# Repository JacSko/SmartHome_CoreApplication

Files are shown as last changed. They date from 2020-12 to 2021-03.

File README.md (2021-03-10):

# SmartHome CoreApplication

## Description
The idea of the project is to gain simple control over home appliance (like lighting).
Main board was desgined to use STM32F411CEU MCU. It communicates with other boards (list below) using different interfaces (I2C, OneWire, USART).
The main responsibility of this part of project is to ensure informations about current temperature and humidity and appliance state.

github_core_diagram

**Main board is connected with:**
- **Relays board** - equipped with 16 relays, supports either 12VDC and 230VAC switching. Board allows to e.g control light state in all rooms. Connection over I2C bus.
- **Inputs board** - board designed to handle 16 inputs (8x 12VDC, 8x 230VAC). Connection over I2C bus with interrupt fired on each input state changed. The bouncing of inputs state has been resolved either by adding debouce capacitor and programatically, by delaying inputs state readout.
- **LED's board** - board equipped with 16 outputs to control led ambient light on staircase placed near to steps. It allows to achieve some lighting effects since can be controlled independently.
- **Sensors board** - Board, where temperature and humidity sensors (DHT11/DHT22 - type is auto-detected in application), also light intense sensor is connected. The communication is realized over OneWire interface, when light intense sensor signal is send in pure analogue form.

## Details
This module is not able to present gathered data.
There is another project [SmartHome_RPi](https://github.com/JacSko/SmartHome_RPi) responsible for presenting received data.
The communication with CoreApplication can be done in two ways:
- **Over WiFi** - ESP01 module is onboard, on startup it creates TCP server, where the RaspberryPi can connects and gets the data. Messages are send in raw bytes mode (for protocol specification see notification_manager.h)
- **Over Bluetooth** - this channel is desgined mainly to provide debug traces, but there are several commands that can be issued in string-based, human readable form (see doc/ dirextory for documntation details)

Project build is managed by CMake.
Core application was prepared using CMSIS bare-metal library without dependencies to external libraries (only appropriate header files are required, but those are part of repository).
Project contains also unit tests, where the original MCU header files has been stubbed to allow compilation.

github_core_sw_diagram

## Building
### Building for target
To build binary, You need to have:
- the arm-none-eabi toolchain
- The st-linkv2 drivers (can be compiled from sources)
- The ST-FLASH utility installed
Once all of those step are ready:
```
cd <project_dir>
mkdir build && cd build
cmake ..
make
```
After the binary can be flashed by issuing:
```
make write
```
### Building Simulation
For details how to use this target, see [SmartHome_Tests](https://github.com/JacSko/SmartHome_Tests)
```
cd <project_dir>
mkdir build_sim
cd build_sim
cmake .. -DSIMULATION=On
make
```
### Building Unit tests
To build unit test, You have to clone googletest repo:
```
cd <project_dir>
cd ext_lib/googletest
git clone https://github.com/google/googletest.git
```
Than run script:
```
./build_and_run_ut.sh
```
### Coverage calculation
Run script:
```
./build_and_run_coverage.sh
```
HTML report will be opened automatically in Firefox, but it can be also found:
```
build_ut/html/coverage.html
```
## TODO
- [ ] EEPROM handling
- [ ] Settings rework to allow read/write settings from EEPROM
- [ ] ADC driver (power supply voltage, light intensity)
- [ ] Flashing over UART (from RaspberryPi module)

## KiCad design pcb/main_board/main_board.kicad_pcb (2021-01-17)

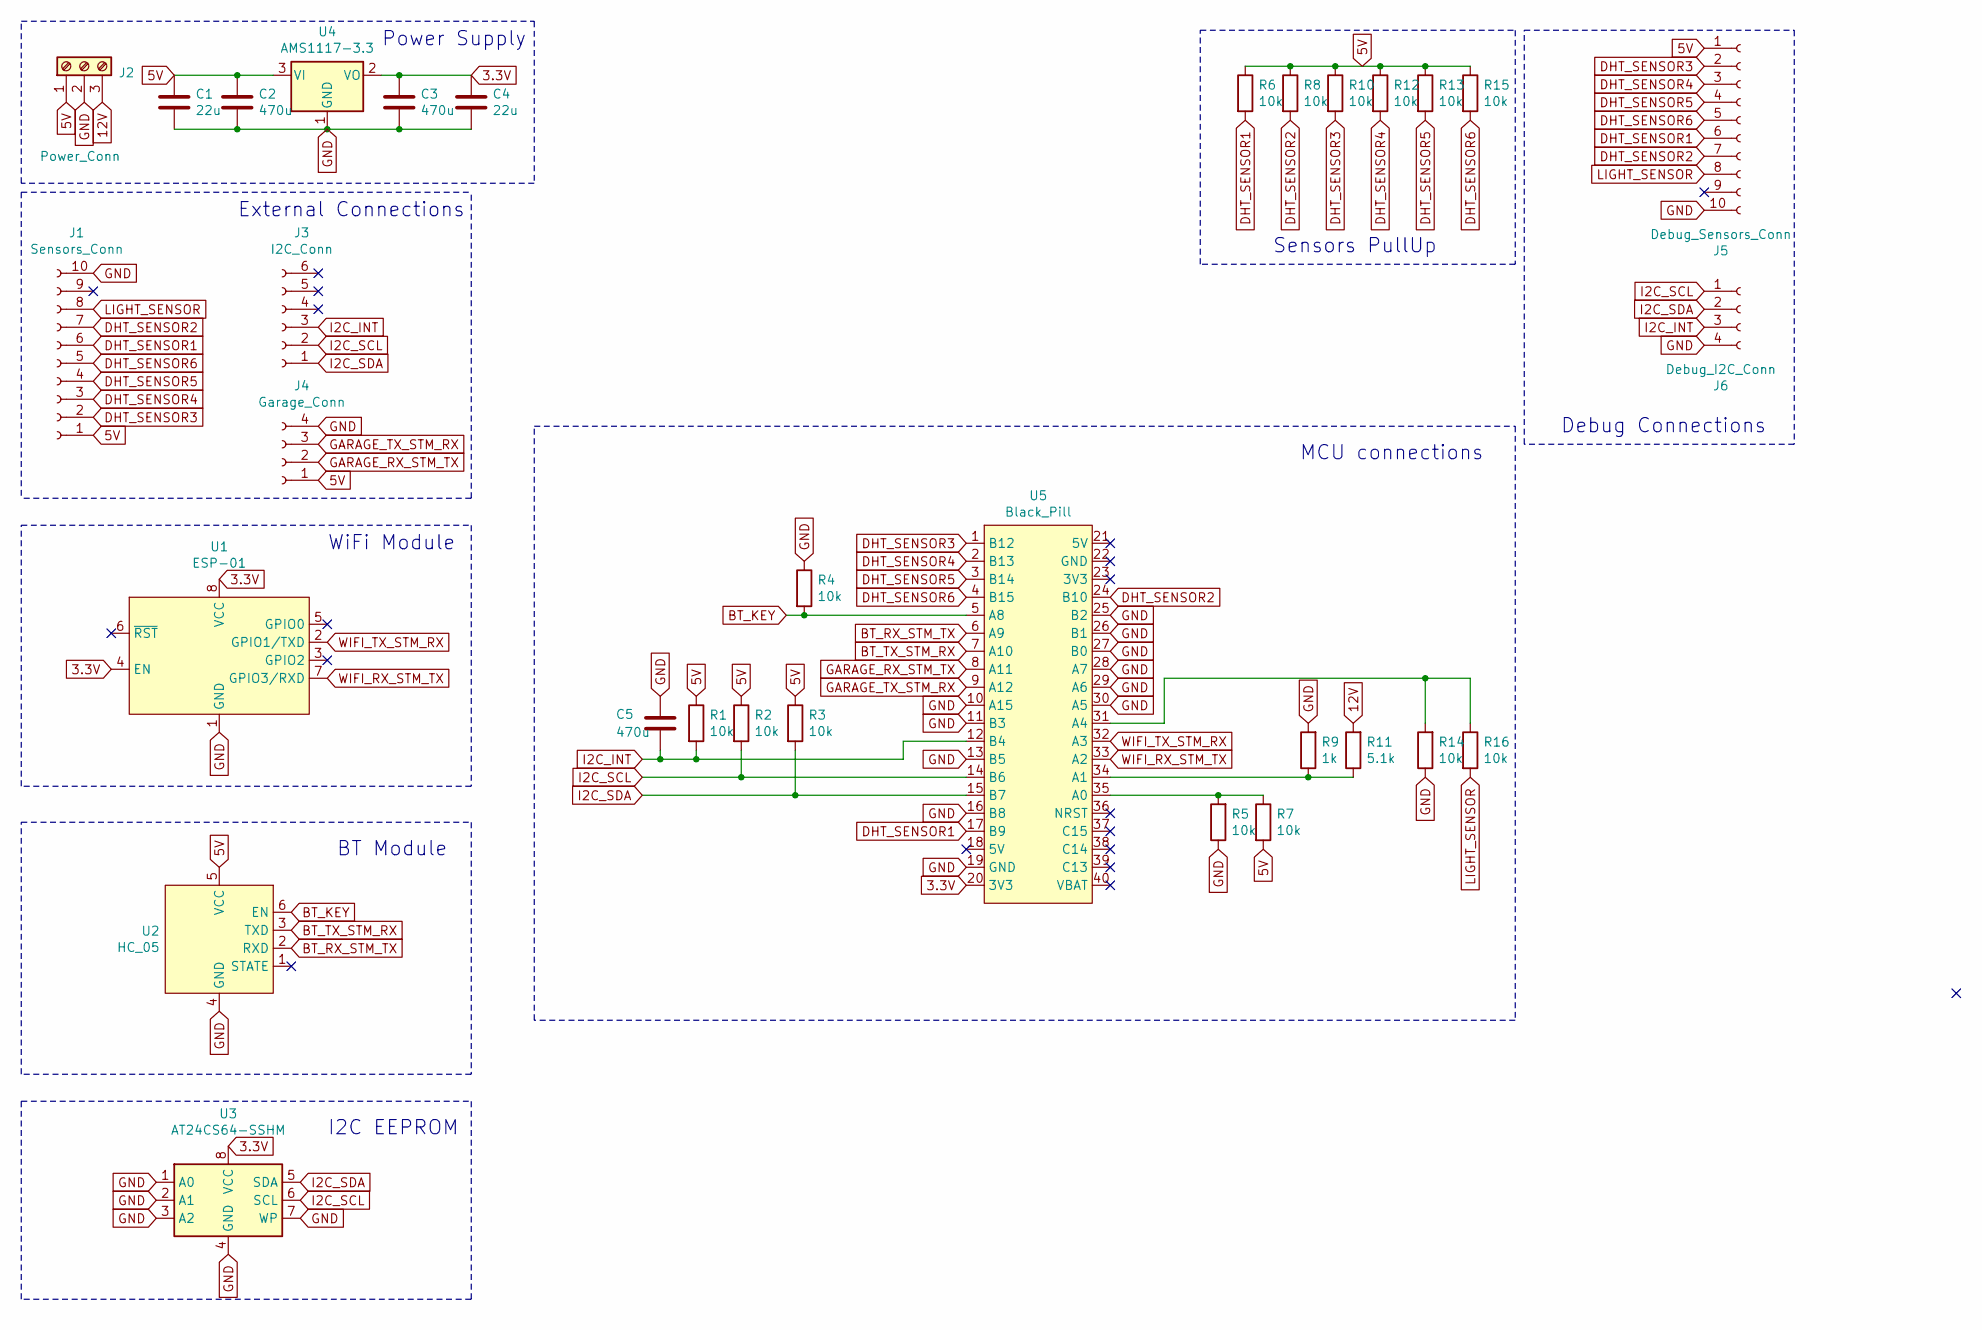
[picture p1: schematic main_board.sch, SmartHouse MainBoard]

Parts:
C1, C4: 22u; CP_EIA-7343-31_Kemet-D_Pad2.25x2.55mm_HandSolder
C2, C3, C5: 470u; CP_Radial_D8.0mm_P2.50mm
J1: Sensors_Conn; PinHeader_1x10_P2.54mm_Vertical
J2: Power_Conn; TerminalBlock_bornier-3_P5.08mm
J3: I2C_Conn; IDC-Header_2x03_P2.54mm_Vertical
J4: Garage_Conn; PinHeader_1x04_P2.54mm_Vertical
J5: Debug_Sensors_Conn; PinHeader_1x10_P2.54mm_Vertical
J6: Debug_I2C_Conn; PinHeader_1x04_P2.54mm_Vertical
R1, R2, R3, R4, R5, R6, R7, R8, R10, R12, R13, R14, R15, R16: 10k; R_1206_3216Metric_Pad1.30x1.75mm_HandSolder
R9: 1k; R_1206_3216Metric_Pad1.30x1.75mm_HandSolder
R11: 5.1k; R_1206_3216Metric_Pad1.30x1.75mm_HandSolder
U1: ESP-01; ESP01
U2: HC_05
U3: AT24CS64-SSHM; SOIC-8_3.9x4.9mm_P1.27mm
U4: AMS1117-3.3; SOT-223-3_TabPin2
U5: Black_Pill; Black_pill

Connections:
3.3V: C3.1, C4.1, U1.4 (EN), U1.8 (VCC), U3.8 (VCC), U4.2 (VO), U5.20 (3V3)
5V: C1.1, C2.1, J1.1, J2.1, J4.1, J5.1, R1.1, R2.1, R3.1, R6.1, R7.2, R8.1, R10.1, R12.1, R13.1, R15.1, U2.5 (VCC), U4.3 (VI)
12V: J2.3, R11.2
BT_KEY: R4.2, U2.6 (EN), U5.5 (A8)
BT_RX_STM_TX: U2.2 (RXD), U5.6 (A9)
BT_TX_STM_RX: U2.3 (TXD), U5.7 (A10)
DHT_SENSOR1: J1.6, J5.6, R6.2, U5.17 (B9)
DHT_SENSOR2: J1.7, J5.7, R8.2, U5.24 (B10)
DHT_SENSOR3: J1.2, J5.2, R10.2, U5.1 (B12)
DHT_SENSOR4: J1.3, J5.3, R12.2, U5.2 (B13)
DHT_SENSOR5: J1.4, J5.4, R13.2, U5.3 (B14)
DHT_SENSOR6: J1.5, J5.5, R15.2, U5.4 (B15)
GARAGE_RX_STM_TX: J4.2, U5.8 (A11)
GARAGE_TX_STM_RX: J4.3, U5.9 (A12)
GND: C1.2, C2.2, C3.2, C4.2, C5.1, J1.10, J2.2, J4.4, J5.10, J6.4, R4.1, R5.1, R9.2, R14.1, U1.1 (GND), U2.4 (GND), U3.1 (A0), U3.2 (A1), U3.3 (A2), U3.4 (GND), U3.7 (WP), U4.1 (GND), U5.10 (A15), U5.11 (B3), U5.13 (B5), U5.16 (B8), U5.19 (GND), U5.25 (B2), U5.26 (B1), U5.27 (B0), U5.28 (A7), U5.29 (A6), U5.30 (A5)
I2C_INT: C5.2, J3.3, J6.3, R1.2, U5.12 (B4)
I2C_SCL: J3.2, J6.1, R2.2, U3.6 (SCL), U5.14 (B6)
I2C_SDA: J3.1, J6.2, R3.2, U3.5 (SDA), U5.15 (B7)
LIGHT_SENSOR: J1.8, J5.8, R16.2
unnamed: R5.2, R7.1, U5.35 (A0)
unnamed: R9.1, R11.1, U5.34 (A1)
unnamed: R14.2, R16.1, U5.31 (A4)
WIFI_RX_STM_TX: U1.7 (GPIO3/RXD), U5.33 (A2)
WIFI_TX_STM_RX: U1.2 (GPIO1/TXD), U5.32 (A3)

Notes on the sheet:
WiFi Module
BT Module
I2C EEPROM
Debug Connections
Sensors PullUp
MCU connections
External Connections
Power Supply

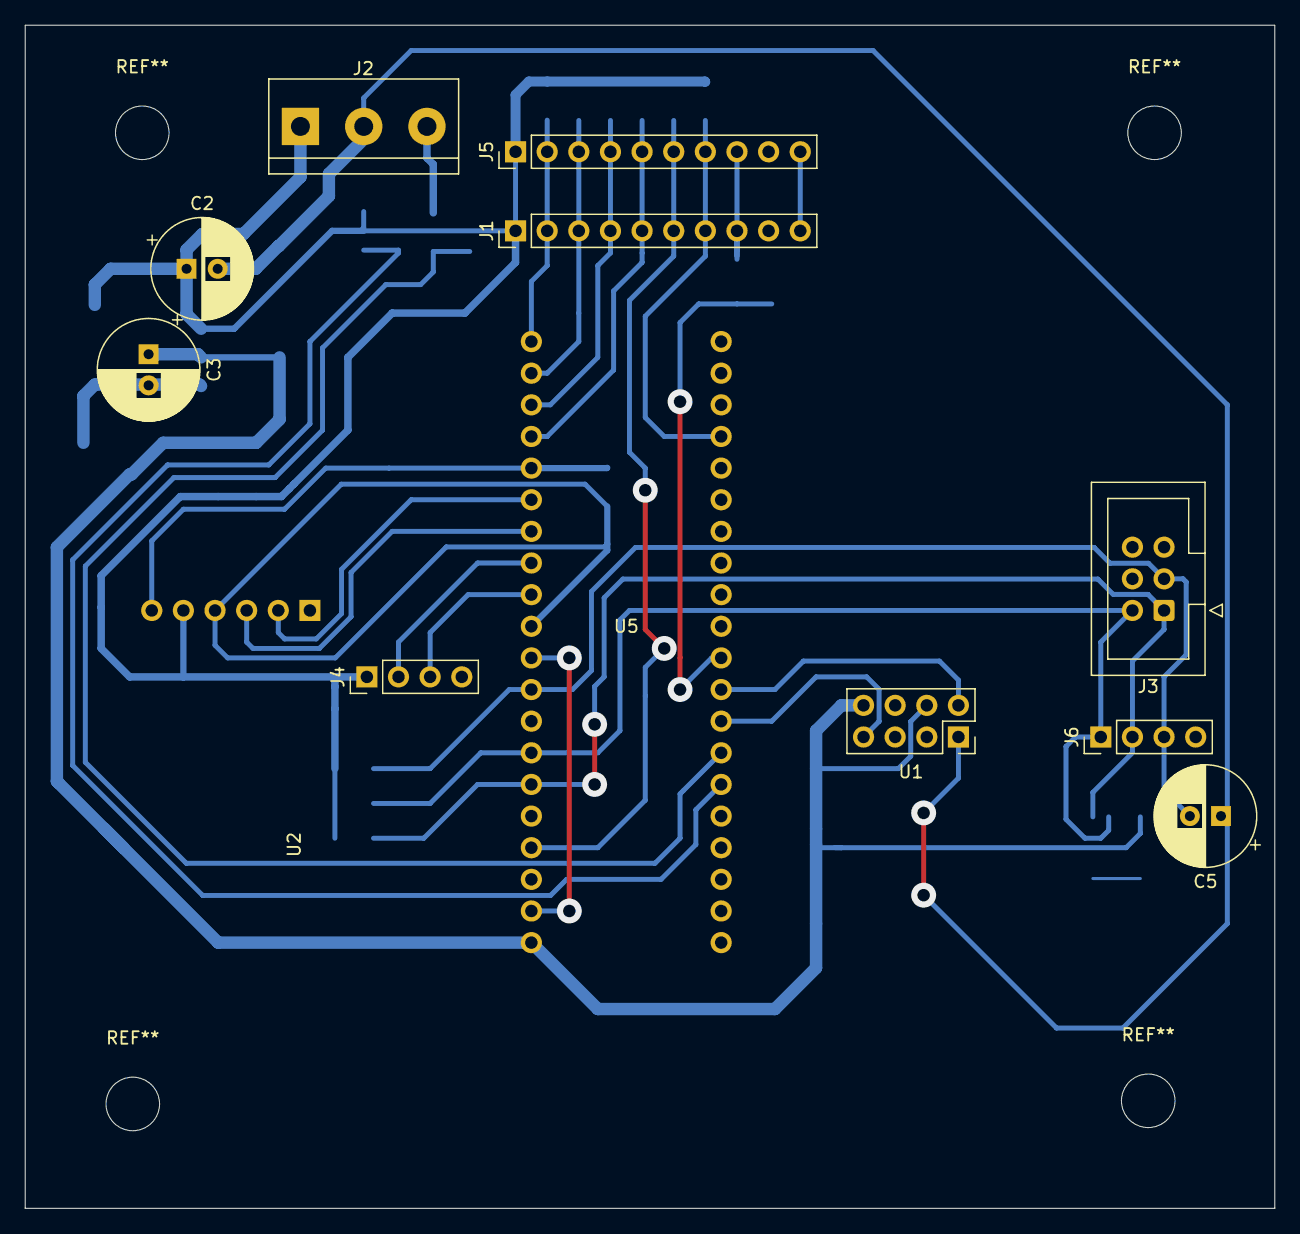
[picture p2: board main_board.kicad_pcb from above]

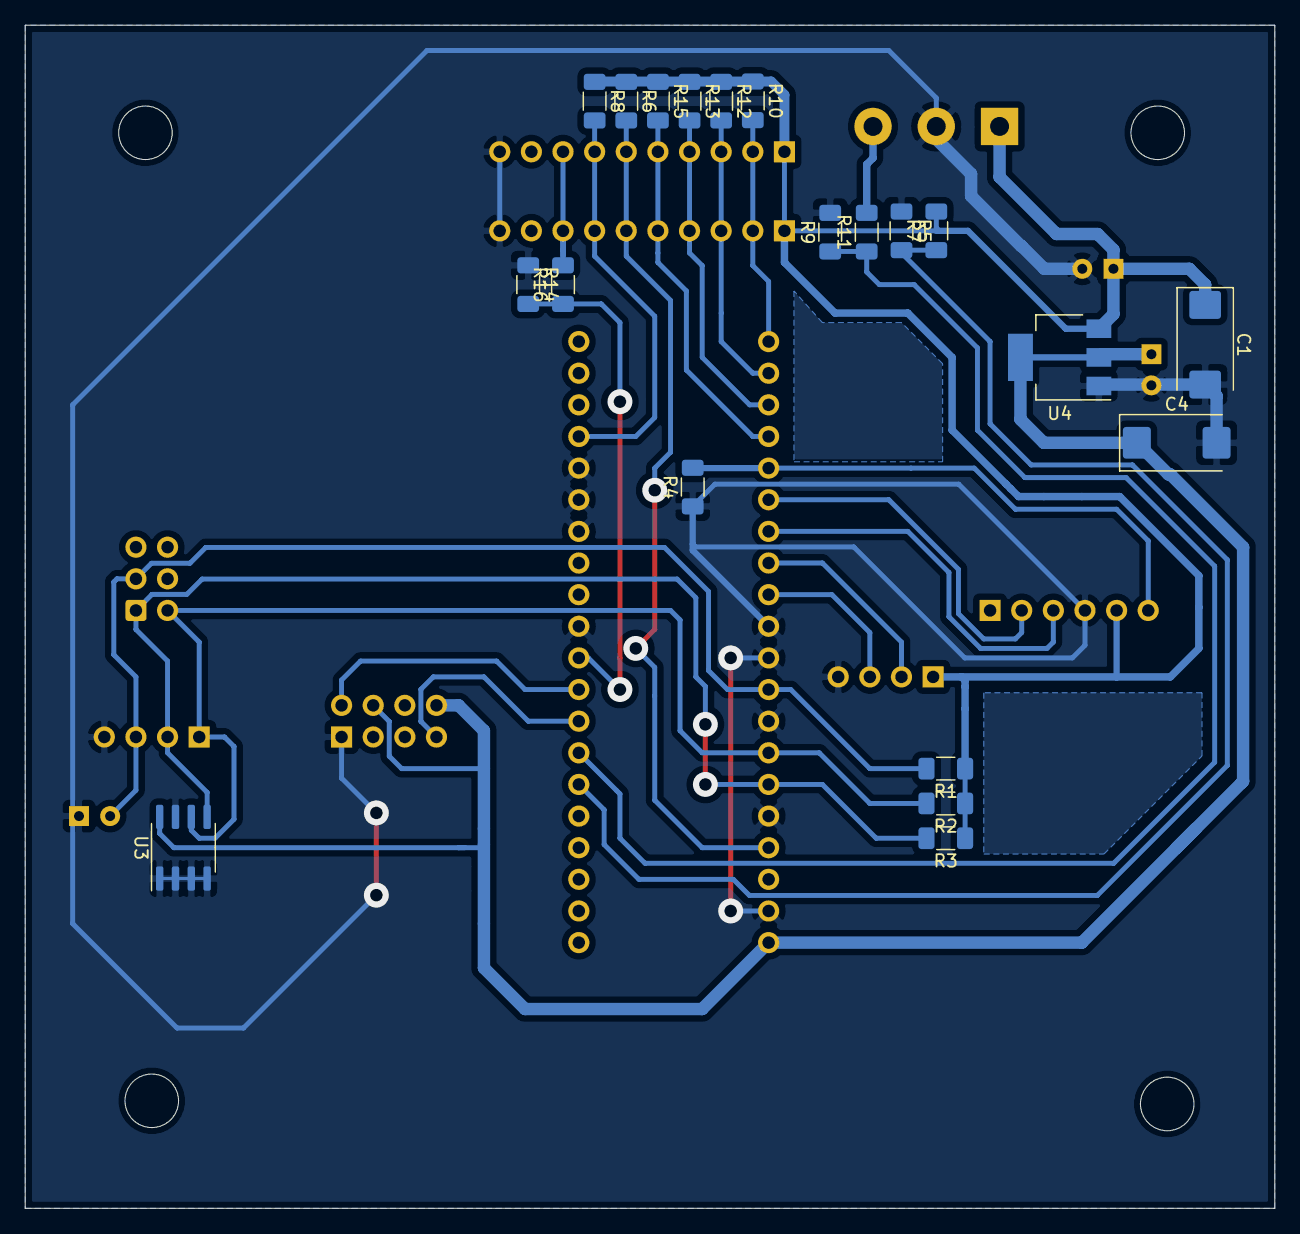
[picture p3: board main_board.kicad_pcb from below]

Board: 2 copper layers, 100.3 x 95.0 mm, 32 parts (20 on the bottom side), 24 nets.

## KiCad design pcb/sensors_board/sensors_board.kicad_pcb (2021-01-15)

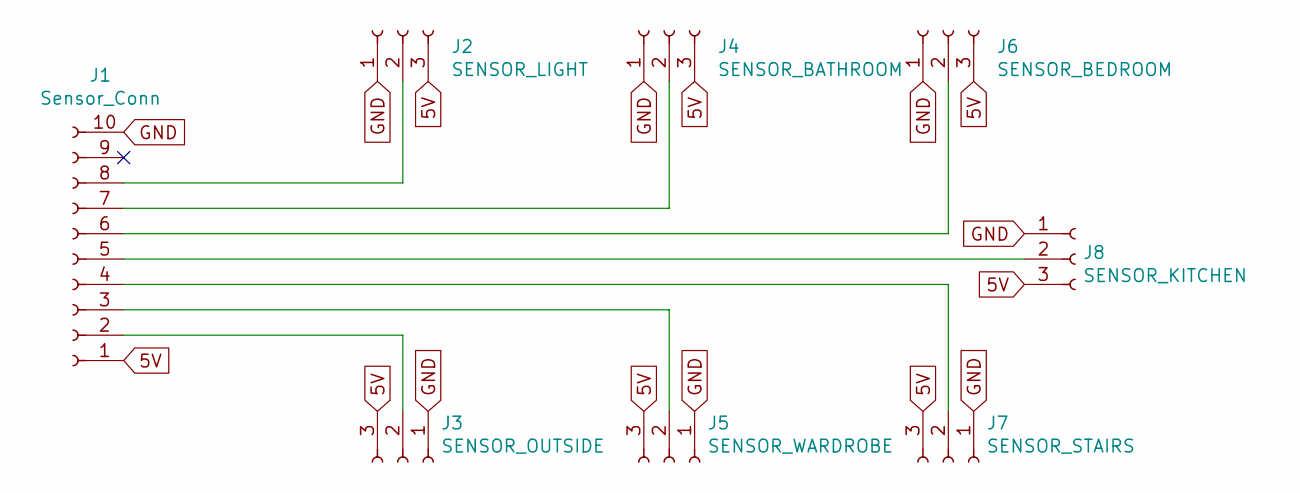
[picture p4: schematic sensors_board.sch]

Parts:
J1: Sensor_Conn; PinHeader_1x10_P2.54mm_Vertical
J2: SENSOR_LIGHT; TerminalBlock_bornier-3_P5.08mm
J3: SENSOR_OUTSIDE; TerminalBlock_bornier-3_P5.08mm
J4: SENSOR_BATHROOM; TerminalBlock_bornier-3_P5.08mm
J5: SENSOR_WARDROBE; TerminalBlock_bornier-3_P5.08mm
J6: SENSOR_BEDROOM; TerminalBlock_bornier-3_P5.08mm
J7: SENSOR_STAIRS; TerminalBlock_bornier-3_P5.08mm
J8: SENSOR_KITCHEN; TerminalBlock_bornier-3_P5.08mm

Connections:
5V: J1.1, J2.3, J3.3, J4.3, J5.3, J6.3, J7.3, J8.3
GND: J1.10, J2.1, J3.1, J4.1, J5.1, J6.1, J7.1, J8.1
unnamed: J1.2, J3.2
unnamed: J1.3, J5.2
unnamed: J1.4, J7.2
unnamed: J1.5, J8.2
unnamed: J1.6, J6.2
unnamed: J1.7, J4.2
unnamed: J1.8, J2.2

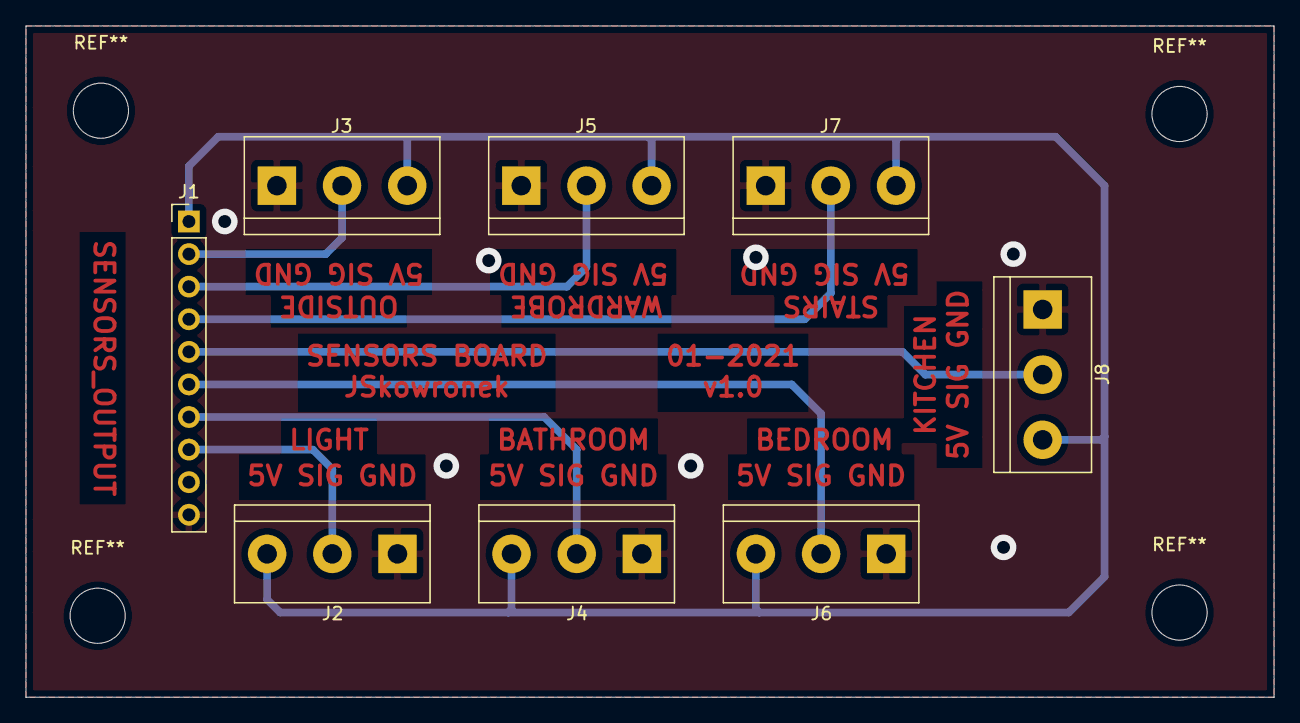
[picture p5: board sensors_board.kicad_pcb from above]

Board: 2 copper layers, 97.3 x 52.3 mm, 8 parts (0 on the bottom side), 9 nets.

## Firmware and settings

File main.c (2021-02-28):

#include <stdlib.h>
#include "stm32f4xx.h"
#include "time_counter.h"
#include "wifi_manager.h"
#include "uart_engine.h"
#include "bt_engine.h"
#include "task_scheduler.h"
#include "command_parser.h"
#include "Logger.h"
#include "i2c_driver.h"
#include "inputs_board.h"
#include "relays_board.h"
#include "stairs_led_module.h"
#include "env_monitor.h"
#include "bathroom_fan.h"
#include "system_timestamp.h"
#include "notification_manager.h"
#include "system_config_values.h"

#ifdef SIMULATION
#include "hw_stub.h"
#endif

/**
 * 	System config:
 * 	HSI - 16MHz
 * 	PLL_M - 16
 * 	PLL_N - 400
 * 	PLL_P - 4
 * 	PLL_Q - 7
 *
 * 	PLL clock - 100MHz
 *
 * 	HCLK - 100MHz
 * 	PCLK2 - 50MHz
 * 	PCLK1 - 25MHz
 *
 * 	AHB_prescaler - 1 - 100MHz
 *    APB1 prescaler - 2 - 50MHz
 *    APB2 prescaler - 1 - 100MHz
 *
 *
 */


void sm_setup_int_priorities()
{
   NVIC_SetPriorityGrouping(0x05);
   uint32_t prio;
   prio = NVIC_EncodePriority(0x05, -1, 0);
   NVIC_SetPriority(SysTick_IRQn, prio);

   /*
    * TIM4 is the timer used to controlling timeout on many synchronous function calls
    * therefore it has to have higher priority (to be able to interrupt systick interrupt).
    * Sometimes sync function are called from scheduler at high priority (called directly from scheduler interrupt)
    * and in such case TIM4 interrupt cannot be fired.
    */
   prio = NVIC_EncodePriority(0x05, -2, 0);
   NVIC_SetPriority(TIM4_IRQn, prio);
   prio = NVIC_EncodePriority(0x05, 2, 0);
   NVIC_SetPriority(USART1_IRQn, prio);

}


int main(void)
{
   sm_setup_int_priorities();

   ts_init();
	time_init();
	sch_initialize();

	/* BTengine is module shared between logger and command parser, therefore is always initialized */
	BT_Config config = {UART_COMMON_BAUD_RATE, UART_COMMON_BUFFER_SIZE, UART_COMMON_STRING_SIZE};
	btengine_initialize(&config);
#ifdef SIMULATION
	hwstub_init();
	stm_stub_init();
#endif
   if (i2c_initialize() != RETURN_OK)
   {
      logger_send(LOG_ERROR, __func__, "Cannot initialize I2C driver");
   }
   if (dht_initialize() != RETURN_OK)
   {
      logger_send(LOG_ERROR, __func__, "Cannot initialize DHT driver");
   }

   /* set timeouts for I2C and DHT */
   i2c_set_timeout(I2C_TRANSACTION_TIMEOUT_MS);
   dht_set_timeout(DHT_TRANSACTION_TIMEOUT_MS);


#ifdef SH_USE_LOGGER
   if (logger_initialize(UART_COMMON_STRING_SIZE) != RETURN_OK)
   {
      logger_send(LOG_ERROR, __func__, "Cannot init BT engine!");
   }
   logger_enable();
   logger_send(LOG_DEBUG, __func__, "Booting up!");
   logger_set_group_state(LOG_DEBUG, LOGGER_DEBUG_GROUP_STATE);
   logger_set_group_state(LOG_DHT_DRV, LOGGER_DHTDRV_GROUP_STATE);
   logger_set_group_state(LOG_WIFI_MANAGER, LOGGER_WIFIMGR_GROUP_STATE);
   logger_set_group_state(LOG_WIFI_DRIVER, LOGGER_WIFIDRV_GROUP_STATE);
   logger_set_group_state(LOG_I2C_DRV, LOGGER_I2CDRV_GROUP_STATE);
   logger_set_group_state(LOG_INPUTS, LOGGER_INPUTS_GROUP_STATE);
   logger_set_group_state(LOG_RELAYS, LOGGER_RELAYS_GROUP_STATE);
   logger_set_group_state(LOG_ENV, LOGGER_ENV_GROUP_STATE);
   logger_set_group_state(LOG_SLM, LOGGER_SLM_GROUP_STATE);
   logger_set_group_state(LOG_FAN, LOGGER_SLM_GROUP_STATE);
   if (logger_register_sender(&btengine_send_string) != RETURN_OK)
   {
      logger_send(LOG_ERROR, __func__, "Cannot register BT sender!");
   }
#endif
   logger_send(LOG_ERROR, __func__, "Booting started!");


#ifdef SH_USE_WIFI
   WIFI_UART_Config wifi_cfg = {UART_COMMON_BAUD_RATE, UART_COMMON_BUFFER_SIZE, UART_COMMON_STRING_SIZE};
   if (wifimgr_initialize(&wifi_cfg) != RETURN_OK)
   {
      logger_send(LOG_ERROR, __func__, "Cannot initiailize wifi manager!");
   }
#endif


#ifdef SH_USE_CMD_PARSER
   cmd_register_sender(&btengine_send_string);

	if (btengine_register_callback(&cmd_handle_data) != RETURN_OK)
	{
		logger_send(LOG_ERROR, __func__, "Cannot add BT callback!");
	}
#endif


#ifdef SH_USE_INPUTS
	INPUTS_CONFIG inp_cfg;
	INPUT_ID INPUTS_MATCH_CONFIG [] = INPUTS_MATCH;
	for (uint8_t i = 0; i < INPUTS_MAX_INPUT_LINES; i++)
	{
	   inp_cfg.items[i].item = INPUT_ENUM_COUNT;
	   inp_cfg.items[i].input_no = 0;
	}
	inp_cfg.address = INPUTS_I2C_ADDRESS;
   uint8_t inp_arr_idx = 0;
   for (uint8_t i = 1; i < (sizeof(INPUTS_MATCH_CONFIG)/sizeof(INPUTS_MATCH_CONFIG[0])); i++)
   {
      if (INPUTS_MATCH_CONFIG[i] != INPUT_ENUM_COUNT)
      {
         inp_cfg.items[inp_arr_idx].item = INPUTS_MATCH_CONFIG[i]; inp_cfg.items[inp_arr_idx].input_no = i;
         inp_arr_idx++;
      }
   }
   if (inp_initialize(&inp_cfg) != RETURN_OK)
   {
      logger_send(LOG_ERROR, __func__, "Cannot initialize Inputs board");
   }
#endif


#ifdef SH_USE_RELAYS
   RELAYS_CONFIG rel_cfg;
   RELAY_ID RELAYS_MATCH_CONFIG [] = RELAYS_MATCH;
   for (uint8_t i = 0; i < RELAYS_BOARD_COUNT; i++)
   {
      rel_cfg.items[i].id = RELAY_ID_ENUM_MAX;
      rel_cfg.items[i].relay_no = 0;
   }
   rel_cfg.address = RELAYS_I2C_ADDRESS;
   uint8_t rel_arr_idx = 0;
   for (uint8_t i = 1; i < (sizeof(RELAYS_MATCH_CONFIG)/sizeof(RELAYS_MATCH_CONFIG[0])); i++)
   {
      if (RELAYS_MATCH_CONFIG[i] != RELAY_ID_ENUM_MAX)
      {
         rel_cfg.items[rel_arr_idx].id = RELAYS_MATCH_CONFIG[i]; rel_cfg.items[rel_arr_idx].relay_no = i;
         rel_arr_idx++;
      }
   }
   if (rel_initialize(&rel_cfg) != RETURN_OK)
   {
      logger_send(LOG_ERROR, __func__, "Cannot initialize Relays board");
   }
#endif


#ifdef SH_USE_ENV
   ENV_CONFIG env_cfg;
   ENV_MATCH ENV_MATCH_CONFIG [] = ENV_DHT_MATCH;
   env_cfg.measure_running = ENV_LOOP_MEASURE_RUNNING;
   env_cfg.max_cs_rate = ENV_MAX_CHECKSUM_RATE;
   env_cfg.max_nr_rate = ENV_MAX_NORESPONSE_RATE;
   for (uint8_t i = 0; i < (sizeof(ENV_MATCH_CONFIG)/sizeof(ENV_MATCH_CONFIG[0])); i++)
   {
      env_cfg.items[i].env_id = ENV_MATCH_CONFIG[i].env_id; env_cfg.items[i].dht_id = ENV_MATCH_CONFIG[i].dht_id;
   }
   if (env_initialize(&env_cfg) != RETURN_OK)
   {
      logger_send(LOG_ERROR, __func__, "Cannot initialize ENV module");
   }
#endif


#ifdef SH_USE_FAN
   FAN_CONFIG fan_cfg;
   fan_cfg.fan_humidity_threshold = FAN_HUMIDITY_THRESHOLD;
   fan_cfg.fan_threshold_hysteresis = FAN_THRESHOLD_HYSTERESIS;
   fan_cfg.max_working_time_s = FAN_MAX_WORKING_TIME_S;
   fan_cfg.min_working_time_s = FAN_MIN_WORKING_TIME_S;
   if (fan_initialize(&fan_cfg) != RETURN_OK)
   {
      logger_send(LOG_ERROR, __func__, "Cannot initialize FAN module");
   }
#endif


#ifdef SH_USE_SLM
   SLM_CONFIG slm_cfg;
   slm_cfg.address = SLM_I2C_ADDRESS;
   slm_cfg.off_effect_mode = SLM_OFF_EFFECT;
   slm_cfg.program_id = SLM_DEFAULT_PROGRAM_ID;
   if(slm_initialize(&slm_cfg) != RETURN_OK)
   {
      logger_send(LOG_ERROR, __func__, "Cannot initialize SLM module");
   }
#endif


#ifdef SH_USE_NTF
   ntfmgr_init();
#endif

   logger_send(LOG_ERROR, __func__, "Booting completed!");

	while (1)
	{
	   i2c_watcher();
	   dht_data_watcher();
		sch_task_watcher(TASKPRIO_LOW);
		btengine_string_watcher();
		wifi_data_watcher();
#ifdef SIMULATION
		hwstub_watcher();
#endif
	}
}

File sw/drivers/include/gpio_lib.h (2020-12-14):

#ifndef PORT_CONFIG_HELPER_H_
#define PORT_CONFIG_HELPER_H_
/* ============================= */
/**
 * @file gpio_lib.h
 *
 * @brief Library provides function allows to set STM32F4xx GPIO's

 * @author Jacek Skowronek
 * @date 13/12/2020
 */
/* ============================= */

/* =============================
 *  Includes of project headers
 * =============================*/
#include "stm32f4xx.h"
/* =============================
 *       Data structures
 * =============================*/

/** Represents all possible GPIO working modes */
typedef enum
{
	/* Push-Pull; Low, Medium, Full, High Speed. */
	gpio_mode_output_PP_LS = 512,
	gpio_mode_output_PP_MS = 576,
	gpio_mode_output_PP_FS = 640,
	gpio_mode_output_PP_HS = 704,
	/* Open-Drain */
	gpio_mode_output_OD_LS = 768,
	gpio_mode_output_OD_MS = 832,
	gpio_mode_output_OD_FS = 896,
	gpio_mode_output_OD_HS = 960,
	/* Open-Drain with weak Pull-Up */
	gpio_mode_output_OD_PU_LS = 784,
	gpio_mode_output_OD_PU_MS = 848,
	gpio_mode_output_OD_PU_FS = 912,
	gpio_mode_output_OD_PU_HS = 976,
	/* Push-Pull in output state. No pullup in input state. Alternate peripheral controls actual state. */
	gpio_mode_AF0_PP_LS = 1024,
	gpio_mode_AF0_PP_MS = 1088,
	gpio_mode_AF0_PP_FS = 1152,
	gpio_mode_AF0_PP_HS = 1216,
	/* Push-Pull when output. Pull-Up when input. */
	gpio_mode_AF0_PP_PU_LS = 1040,
	gpio_mode_AF0_PP_PU_MS = 1104,
	gpio_mode_AF0_PP_PU_FS = 1168,
	gpio_mode_AF0_PP_PU_HS = 1232,
	/* Push-Pull when output. Pull-Down when input. */
	gpio_mode_AF0_PP_PD_LS = 1056,
	gpio_mode_AF0_PP_PD_MS = 1120,
	gpio_mode_AF0_PP_PD_FS = 1184,
	gpio_mode_AF0_PP_PD_HS = 1248,
	/* Open-Drain */
	gpio_mode_AF0_OD_LS = 1280,
	gpio_mode_AF0_OD_MS = 1344,
	gpio_mode_AF0_OD_FS = 1408,
	gpio_mode_AF0_OD_HS = 1472,
	/* Open-Drain when output. Pull-Up when input. */
	gpio_mode_AF0_OD_PU_LS = 1296,
	gpio_mode_AF0_OD_PU_MS = 1360,
	gpio_mode_AF0_OD_PU_FS = 1424,
	gpio_mode_AF0_OD_PU_HS = 1488,
	/* Open-Drain when output. Pull-Down when input. */
	gpio_mode_AF0_OD_PD_LS = 1312,
	gpio_mode_AF0_OD_PD_MS = 1376,
	gpio_mode_AF0_OD_PD_FS = 1440,
	gpio_mode_AF0_OD_PD_HS = 1504,
	gpio_mode_AF1_PP_LS = 1025,
	gpio_mode_AF1_PP_MS = 1089,
	gpio_mode_AF1_PP_FS = 1153,
	gpio_mode_AF1_PP_HS = 1217,
	gpio_mode_AF1_PP_PU_LS = 1041,
	gpio_mode_AF1_PP_PU_MS = 1105,
	gpio_mode_AF1_PP_PU_FS = 1169,
	gpio_mode_AF1_PP_PU_HS = 1233,
	gpio_mode_AF1_PP_PD_LS = 1057,
	gpio_mode_AF1_PP_PD_MS = 1121,
	gpio_mode_AF1_PP_PD_FS = 1185,
	gpio_mode_AF1_PP_PD_HS = 1249,
	gpio_mode_AF1_OD_LS = 1281,
	gpio_mode_AF1_OD_MS = 1345,
	gpio_mode_AF1_OD_FS = 1409,
	gpio_mode_AF1_OD_HS = 1473,
	gpio_mode_AF7_OD_PU_LS = 1303,
	gpio_mode_AF7_OD_PU_MS = 1367,
	gpio_mode_AF7_OD_PU_FS = 1431,
	gpio_mode_AF7_OD_PU_HS = 1495,
	gpio_mode_AF7_OD_PD_LS = 1319,
	gpio_mode_AF7_OD_PD_MS = 1383,
	gpio_mode_AF7_OD_PD_FS = 1447,
	gpio_mode_AF7_OD_PD_HS = 1511,
	gpio_mode_AF8_PP_LS = 1032,
	gpio_mode_AF8_PP_MS = 1096,
	gpio_mode_AF8_PP_FS = 1160,
	gpio_mode_AF8_PP_HS = 1224,
	gpio_mode_AF8_PP_PU_LS = 1048,
	gpio_mode_AF8_PP_PU_MS = 1112,
	gpio_mode_AF8_PP_PU_FS = 1176,
	gpio_mode_AF8_PP_PU_HS = 1240,
	gpio_mode_AF8_PP_PD_LS = 1064,
	gpio_mode_AF8_PP_PD_MS = 1128,
	gpio_mode_AF8_PP_PD_FS = 1192,
	gpio_mode_AF8_PP_PD_HS = 1256,
	gpio_mode_AF8_OD_LS = 1288,
	gpio_mode_AF8_OD_MS = 1352,
	gpio_mode_AF8_OD_FS = 1416,
	gpio_mode_AF8_OD_HS = 1480,
	gpio_mode_AF8_OD_PU_LS = 1304,
	gpio_mode_AF8_OD_PU_MS = 1368,
	gpio_mode_AF8_OD_PU_FS = 1432,
	gpio_mode_AF8_OD_PU_HS = 1496,
	gpio_mode_AF8_OD_PD_LS = 1320,
	gpio_mode_AF8_OD_PD_MS = 1384,
	gpio_mode_AF8_OD_PD_FS = 1448,
	gpio_mode_AF8_OD_PD_HS = 1512,
	gpio_mode_AF9_PP_LS = 1033,
	gpio_mode_AF9_PP_MS = 1097,
	gpio_mode_AF9_PP_FS = 1161,
	gpio_mode_AF9_PP_HS = 1225,
	gpio_mode_AF9_PP_PU_LS = 1049,
	gpio_mode_AF9_PP_PU_MS = 1113,
	gpio_mode_AF9_PP_PU_FS = 1177,
	gpio_mode_AF9_PP_PU_HS = 1241,
	gpio_mode_AF9_PP_PD_LS = 1065,
	gpio_mode_AF9_PP_PD_MS = 1129,
	gpio_mode_AF9_PP_PD_FS = 1193,
	gpio_mode_AF9_PP_PD_HS = 1257,
	gpio_mode_AF9_OD_LS = 1289,
	gpio_mode_AF9_OD_MS = 1353,
	gpio_mode_AF9_OD_FS = 1417,
	gpio_mode_AF9_OD_HS = 1481,
	gpio_mode_AF9_OD_PU_LS = 1305,
	gpio_mode_AF9_OD_PU_MS = 1369,
	gpio_mode_AF9_OD_PU_FS = 1433,
	gpio_mode_AF9_OD_PU_HS = 1497,
	gpio_mode_AF9_OD_PD_LS = 1321,
	gpio_mode_AF9_OD_PD_MS = 1385,
	gpio_mode_AF9_OD_PD_FS = 1449,
	gpio_mode_AF9_OD_PD_HS = 1513,
	gpio_mode_AF10_PP_LS = 1034,
	gpio_mode_AF10_PP_MS = 1098,
	gpio_mode_AF10_PP_FS = 1162,
	gpio_mode_AF10_PP_HS = 1226,
	gpio_mode_AF10_PP_PU_LS = 1050,
	gpio_mode_AF10_PP_PU_MS = 1114,
	gpio_mode_AF10_PP_PU_FS = 1178,
	gpio_mode_AF10_PP_PU_HS = 1242,
	gpio_mode_AF10_PP_PD_LS = 1066,
	gpio_mode_AF10_PP_PD_MS = 1130,
	gpio_mode_AF10_PP_PD_FS = 1194,
	gpio_mode_AF10_PP_PD_HS = 1258,
	gpio_mode_AF1_OD_PU_LS = 1297,
	gpio_mode_AF1_OD_PU_MS = 1361,
	gpio_mode_AF1_OD_PU_FS = 1425,
	gpio_mode_AF1_OD_PU_HS = 1489,
	gpio_mode_AF1_OD_PD_LS = 1313,
	gpio_mode_AF1_OD_PD_MS = 1377,
	gpio_mode_AF1_OD_PD_FS = 1441,
	gpio_mode_AF1_OD_PD_HS = 1505,
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

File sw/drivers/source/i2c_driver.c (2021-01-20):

/* =============================
 *   Includes of common headers
 * =============================*/
#include <stdlib.h>
/* =============================
 *  Includes of project headers
 * =============================*/
#include "stm32f4xx.h"
#include "i2c_driver.h"
#include "Logger.h"
#include "task_scheduler.h"
#include "gpio_lib.h"
/* =============================
 *          Defines
 * =============================*/
#define I2C_DRV_BUFFER_SIZE 32
#define I2C_DEFAULT_TIMEOUT_MS 100
#define I2C_MIN_TIMEOUT_MS 10
#define I2C_MAX_TIMEOUT_MS 500
/* =============================
 *   Internal module functions
 * =============================*/
void i2c_on_timeout();
RET_CODE i2c_validate_timeout(uint16_t timeout);
void i2c_print_buffer(I2C_OP_TYPE type);
I2C_STATUS i2c_get_status();
/* =============================
 *       Internal types
 * =============================*/
typedef enum I2C_STATE
{
   I2C_STATE_IDLE,
   I2C_STATE_STARTED,
   I2C_STATE_ADDRESS_WRITE,
   I2C_STATE_DATA_EXCHANGE,
   I2C_STATE_END_OK,
   I2C_STATE_ERROR,
   I2C_STATE_UNKNOWN,
} I2C_STATE;
typedef struct I2C_DRIVER_TYPE
{
   I2C_STATE state;
   I2C_ADDRESS address;
   I2C_OP_TYPE type;
   uint16_t timeout;
   uint8_t bytes_requested;
   uint8_t bytes_handled;
   uint8_t transaction_ready;
} I2C_DRIVER_TYPE;
/* =============================
 *      Module variables
 * =============================*/
uint8_t I2C_DRV_BUF[I2C_DRV_BUFFER_SIZE];
volatile I2C_DRIVER_TYPE i2c_driver;
I2C_CALLBACK i2c_drv_callback;

RET_CODE i2c_initialize()
{
   logger_send(LOG_I2C_DRV, __func__, "");
   RET_CODE result = RETURN_NOK;
   i2c_driver.state = I2C_STATE_UNKNOWN;
   if (sch_subscribe_and_set(&i2c_on_timeout, TASKPRIO_HIGH, I2C_DEFAULT_TIMEOUT_MS,
                                  TASKSTATE_STOPPED, TASKTYPE_TRIGGER) == RETURN_OK)
   {
      i2c_driver.address = 0;
      i2c_driver.type = I2C_OP_UNKNOWN;
      i2c_driver.timeout = I2C_DEFAULT_TIMEOUT_MS;
      i2c_driver.bytes_requested = 0;
      i2c_driver.bytes_handled = 0;
      i2c_driver.transaction_ready = 0;
      i2c_reset();
      result = RETURN_OK;
   }
   logger_send_if(result != RETURN_OK, LOG_ERROR, __func__, "error");
   return result;
}
void i2c_on_timeout()
{
   if (i2c_driver.state != I2C_STATE_IDLE)
   {
      logger_send(LOG_ERROR,__func__,"timeout");
      i2c_driver.state = I2C_STATE_ERROR;
      i2c_driver.transaction_ready = 1;
   }
}

RET_CODE i2c_write_async(I2C_ADDRESS address, const uint8_t* data, uint8_t size, I2C_CALLBACK callback)
{
   RET_CODE result = RETURN_NOK;
   logger_send(LOG_I2C_DRV, __func__, "writing %u bytes to 0x%x", size, address);
   if (i2c_driver.state == I2C_STATE_IDLE && size <= I2C_DRV_BUFFER_SIZE)
   {
      i2c_driver.address = address;
      i2c_driver.bytes_handled = 0;
      i2c_driver.bytes_requested = size;
      i2c_driver.type = I2C_OP_WRITE;
      i2c_drv_callback = callback;
      for (uint8_t i = 0; i < size; i++)
      {
         I2C_DRV_BUF[i] = data[i];
      }
      I2C1->CR1 |= I2C_CR1_START;
      I2C1->CR1 |= I2C_CR1_ACK;
      sch_trigger_task(&i2c_on_timeout);
      i2c_driver.state = I2C_STATE_STARTED;
      result = RETURN_OK;
   }
   logger_send_if(result != RETURN_OK, LOG_ERROR, __func__, "error");
   return result;
}
I2C_STATUS i2c_write(I2C_ADDRESS address, const uint8_t* data, uint8_t size)
{
   I2C_STATUS result = I2C_STATUS_UNKNOWN;
   if (i2c_write_async(address, data, size, NULL) == RETURN_OK)
   {
      while(i2c_driver.transaction_ready == 0);
      result = i2c_get_status();
      i2c_watcher();
   }
   return result;

}
RET_CODE i2c_read_async(I2C_ADDRESS address, uint8_t size, I2C_CALLBACK callback)
{
   RET_CODE result = RETURN_NOK;
   logger_send(LOG_I2C_DRV, __func__, "reading %u bytes from 0x%x", size, address);
   if (i2c_driver.state == I2C_STATE_IDLE && size <= I2C_DRV_BUFFER_SIZE)
   {
      i2c_driver.address = address;
      i2c_driver.type = I2C_OP_READ;
      i2c_driver.bytes_requested = size;
      i2c_driver.bytes_handled = 0;
      I2C1->CR1 |= I2C_CR1_START;
      I2C1->CR1 |= I2C_CR1_ACK;
      I2C1->CR2 |= I2C_CR2_ITBUFEN;
      i2c_driver.state = I2C_STATE_STARTED;
      i2c_drv_callback = callback;
      sch_trigger_task(&i2c_on_timeout);
      result = RETURN_OK;
   }
   return result;
}
I2C_STATUS i2c_read(I2C_ADDRESS address, uint8_t* data, uint8_t size)
{
   I2C_STATUS result = I2C_STATUS_UNKNOWN;
   if (i2c_read_async(address, size, NULL) == RETURN_OK)
   {
      while(i2c_driver.transaction_ready == 0);
      result = i2c_get_status();
      for (uint8_t i = 0; i < i2c_driver.bytes_handled; i++)
      {
         data[i] = I2C_DRV_BUF[i];
      }
      i2c_watcher();
   }
   return result;
}

void i2c_print_buffer(I2C_OP_TYPE type)
{
   if (logger_get_group_state(LOG_I2C_DRV) == LOGGER_GROUP_ENABLE)
   {
      char data_dump [80];
      uint8_t idx = 0;
      for (uint8_t i = 0; i < i2c_driver.bytes_handled; i++)
      {
         idx += string_format(&data_dump[idx], "%x ", I2C_DRV_BUF[i]);
      }
      logger_send(LOG_I2C_DRV, __func__, "%s:%s", type == I2C_OP_WRITE? "WRITE" : "READ", data_dump);
   }
}

uint16_t i2c_get_timeout()
{
   return i2c_driver.timeout;
}
RET_CODE i2c_set_timeout(uint16_t timeout)
{
   RET_CODE result = RETURN_NOK;
   if (i2c_validate_timeout(timeout) == RETURN_OK)
   {
      logger_send(LOG_I2C_DRV, __func__, "new timeout %d", timeout);
      i2c_driver.timeout = timeout;
      result = sch_set_task_period(&i2c_on_timeout, timeout);
   }
   return result;
}

RET_CODE i2c_validate_timeout(uint16_t timeout)
{
   RET_CODE result = RETURN_NOK;
   if (timeout >= I2C_MIN_TIMEOUT_MS && timeout <= I2C_MAX_TIMEOUT_MS)
   {
      result = RETURN_OK;
   }
   logger_send_if(result != RETURN_OK, LOG_ERROR, __func__, "invalid timeout", timeout);
   return result;
}

void i2c_reset()
{
   logger_send(LOG_ERROR, __func__, "resetting i2c");
   RCC->APB1RSTR |= RCC_APB1RSTR_I2C1RST;
   __DSB();
   RCC->APB1RSTR &= ~RCC_APB1RSTR_I2C1RST;
   __DSB();
   RCC->AHB1ENR |= RCC_AHB1ENR_GPIOBEN;
   __DSB();
   RCC->APB1ENR |= RCC_APB1ENR_I2C1EN;
   __DSB();
   I2C1->CR1 |= I2C_CR1_SWRST;
   I2C1->CR1 &= ~I2C_CR1_SWRST;
   gpio_pin_cfg(GPIOB, PB6, gpio_mode_AF4_OD_HS);
   gpio_pin_cfg(GPIOB, PB7, gpio_mode_AF4_OD_HS);
   I2C1->CR2 |= 0x32;   //APB2 clock 50MHz
   I2C1->CR2 |= I2C_CR2_ITEVTEN;
   I2C1->CCR |= 0xFA;   // SCL speed 100kHz (0xB4==180d, how many clock ticks to change state on SCL line)
   I2C1->TRISE |= 0x25; //25
   I2C1->CR2 |= I2C_CR2_ITEVTEN;
   I2C1->CR1 |= I2C_CR1_PE | I2C_CR1_ACK;
   i2c_driver.state = I2C_STATE_IDLE;
   NVIC_EnableIRQ(I2C1_EV_IRQn);
}
void i2c_deinitialize()
{
   i2c_driver.state = I2C_STATE_UNKNOWN;
   i2c_driver.type = I2C_OP_UNKNOWN;
}

I2C_STATUS i2c_get_status()
{
   I2C_STATUS result = i2c_driver.state == I2C_STATE_END_OK? I2C_STATUS_OK : I2C_STATUS_ERROR;
   return result;
}
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

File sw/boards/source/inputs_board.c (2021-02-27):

/* =============================
 *   Includes of common headers
 * =============================*/
#include <stdlib.h>
/* =============================
 *  Includes of project headers
 * =============================*/
#include "inputs_board.h"
#include "task_scheduler.h"
#include "Logger.h"
#include "inputs_interrupt_handler.h"
/* =============================
 *          Defines
 * =============================*/
#define INPUTS_CALLBACK_MAX_SIZE 5
#define INPUTS_AUTOUPDATE_STATE 1
#define INPUTS_INTERRUPT_STATE 1
#define INPUTS_AUTOUPDATE_DEF_TIME_MS 5000
#define INPUTS_AUTOUPDATE_MIN_TIME_MS 100
#define INPUTS_AUTOUPDATE_MAX_TIME_MS 30000
#define INPUTS_DEBOUNCE_DEF_TIME_MS 100
#define INPUTS_DEBOUNCE_MIN_TIME_MS 20
#define INPUTS_DEBOUNCE_MAX_TIME_MS 3000
/* =============================
 *   Internal module functions
 * =============================*/
void inp_read_inputs();
void inp_on_timeout();
void inp_notify_inputs_change(const INPUT_STATUS* new_inputs);
uint16_t inp_input_to_mask(uint8_t input);
RET_CODE inp_validate_debounce_time(uint16_t time);
RET_CODE inp_validate_autoupdate_time(uint16_t time);
void inp_notify_callbacks(const INPUT_STATUS* status);
void inp_parse_state(uint16_t state, INPUT_STATUS* buffer);
/* =============================
 *       Internal types
 * =============================*/
typedef struct INPUT_MODULE
{
   INPUTS_CONFIG cfg;
   uint16_t current_inputs;
   uint8_t interrupt_enabled;
   uint16_t debounce_time;
   uint8_t autoupdate_enabled;
   uint16_t autoupdate_time;
   INPUT_STATUS current_states [INPUTS_MAX_INPUT_LINES];

} INPUT_MODULE;
/* =============================
 *      Module variables
 * =============================*/
INPUT_MODULE inp_module;
void (*INP_CALLBACKS[INPUTS_CALLBACK_MAX_SIZE])(INPUT_STATUS status);

RET_CODE inp_initialize(const INPUTS_CONFIG* config)
{
   logger_send(LOG_INPUTS, __func__, "");
   RET_CODE result = RETURN_NOK;
   inp_module.autoupdate_enabled = INPUTS_AUTOUPDATE_STATE;
   inp_module.autoupdate_time = INPUTS_AUTOUPDATE_DEF_TIME_MS;
   inp_module.interrupt_enabled = INPUTS_INTERRUPT_STATE;
   inp_module.debounce_time = INPUTS_DEBOUNCE_DEF_TIME_MS;
   if (config)
   {
      for (uint8_t i = 0; i < INPUTS_MAX_INPUT_LINES; i++)
      {
         inp_module.current_states[i].id = inp_module.cfg.items[i].item;
         inp_module.current_states[i].state = INPUT_STATE_INACTIVE;
      }
      inp_module.cfg = *config;
      /* task for inputs autoupdate */
      result = sch_subscribe_and_set(&inp_read_inputs, TASKPRIO_LOW, inp_module.autoupdate_time,
               inp_module.autoupdate_enabled? TASKSTATE_RUNNING : TASKSTATE_STOPPED, TASKTYPE_PERIODIC);
      if (result == RETURN_OK)
      {
         /* task for debouncing */
         result = sch_subscribe_and_set(&inp_on_timeout, TASKPRIO_LOW, inp_module.debounce_time,
                  inp_module.interrupt_enabled? TASKSTATE_RUNNING : TASKSTATE_STOPPED, TASKTYPE_TRIGGER);
      }
   }
   int_handler_init();
   logger_send_if(result != RETURN_OK, LOG_ERROR, __func__, "error");
   return result;
}
void inp_deinitialize()
{
   sch_unsubscribe(&inp_on_timeout);
   sch_unsubscribe(&inp_read_inputs);
   for (uint8_t i = 0; i < INPUTS_CALLBACK_MAX_SIZE; i++)
   {
      INP_CALLBACKS[i] = NULL;
   }
}

INPUT_STATE inp_get(INPUT_ID id)
{
   INPUT_STATE result = INPUT_STATE_INACTIVE;
   for (uint8_t i = 0; i < INPUTS_MAX_INPUT_LINES; i++)
   {
      if (inp_module.current_states[i].id == id)
      {
         result = inp_module.current_states[i].state;
         break;
      }
   }
   return result;
}
RET_CODE inp_get_all(INPUT_STATUS* buffer)
{
   RET_CODE result = RETURN_ERROR;
   if (buffer)
   {
      for (uint8_t i = 0; i < INPUTS_MAX_INPUT_LINES; i++)
      {
         buffer[i] = inp_module.current_states[i];
      }
      result = RETURN_OK;
   }
   return result;
}
RET_CODE inp_read_all(INPUT_STATUS* buffer)
{
   RET_CODE result = RETURN_NOK;
   uint8_t data [2];
   if (buffer)
   {
      if (i2c_read(inp_module.cfg.address + 1, data, 2) == I2C_STATUS_OK)
      {
         uint16_t new_state = data[0];
         new_state |= (data[1] << 8);
         new_state = ~new_state;
         inp_parse_state(new_state, buffer);
         result = RETURN_OK;
      }
   }
   return result;
}
RET_CODE inp_get_config(INPUTS_CONFIG* buffer)
{
   RET_CODE result = RETURN_ERROR;
   if (buffer)
   {
      *buffer = inp_module.cfg;
      result = RETURN_OK;
   }
   return result;
}
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

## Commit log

2020-10-30 Initial commit
    Two build targets (STM and UT) are working
    [Documentation.ods]
2020-10-30 UT framework added
2020-11-01 uartengine started, stm stub reworked
    [gpio_lib.c, gpio_lib.h, main.c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]
2020-11-01 uartengine moved to drivers module
2020-11-02 Added UT for uartengine, main function prepared to HW tests
2020-11-02 disable all interrupt when writing data to uart buffer
2020-11-04 uartengine tested, CR LF ending case added
    [stm32f4discovery.cfg]
2020-11-11 Fix for time_counter
    [stm32f4discovery.cfg]
2020-11-15 UART_ENGINE ignores CR and calls callback only if received strlen is greated than 0
2020-11-15 fix uart_engine compile warning
    [uart_engine.c]
2020-11-18 wifi driver implementing started
2020-11-22 uartengine now allows to check for string in synchronous way
2020-11-27 Fix for receiving UART data
    [uart_engine.c]
2020-11-27 Wifi driver implementation - next part
2020-11-28 uart engine ready to notify about received strings and bytes
2020-11-28 uartengine mock updated to latest changes
2020-11-28 wifi driver development
2020-11-28 HW checkout, increased wait time for OK response when connecting to wireless network
2020-11-30 WiFi driver now use USART2, BT engine use USART1, Wifi interface description added, not needed inclusions removed
2020-12-03 fix for reading time from NTP server
    [main.c, wifi_driver.c]
2020-12-04 Logger rework - allow variable argument, possible fix for reading data from NTP, uartengine tests developed
    [main.c, uart_engine.c, wifi_driver.c]
2020-12-05 wifi_reset() added to wifi driver
2020-12-08 Workaround for reading NTP time at initialization stage
    [wifi_driver.c]
2020-12-10 Fix for receiving data from socket
    [bt_engine.c, command_parser.c, main.c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]
2020-12-10 uartengine now uses config from init instead of hardcoded
2020-12-13 Documentation - added commands for wifimgr
    [Documentation.ods]
2020-12-13 drivers doxygen adding in progress
2020-12-14 Doxygen added for drivers
2020-12-14 string_formatter precision handling, documentation updated
    [Documentation.ods]
2020-12-15 documentation update
    [Documentation.ods]
2020-12-15 DHT driver skeleton added
2020-12-15 DHT driver development
    [Documentation.ods]
2020-12-17 fixes for valgrind issues
    [bt_engine.c, uart_engine.c]
2020-12-17 DHT driver cleanup
2020-12-17 some major fixes to dht driver and scheduler
    [dht_driver.c, main.c]
2020-12-18 I2C skeleton added
2020-12-18 ods documentation update
    [Documentation.ods]
2020-12-18 i2c driver development
2020-12-18 i2c driver development end
2020-12-19 debugs added to I2C driver
2020-12-19 app DHT driver change in runtime
2020-12-19 little cleanup in i2c driver
2020-12-19 i2c driver UT added
2020-12-20 i2c driver removed not needed debug
2020-12-22 Inputs module added, UT added, documentation updated
    [Documentation.ods]
2020-12-22 interface for relays_board added
2020-12-26 relays module first implementation added
    [Documentation.ods]
2020-12-27 relays debugs added
2020-12-27 gpio_lib merged to drivers
2020-12-27 relays and inputs shortly tested
    [main.c]
2020-12-28 bathroom fan skeleton added
2020-12-29 fan module added
2020-12-30 added function to read inputs directly from board
2020-12-30 rel_read_all function added to read relays directly from board
2020-12-30 read relays state on startup
2020-12-30 stairs led module skeleton added
2021-01-06 stairs led module implementation ongoing
2021-01-10 added methods to send bytes over UART
2021-01-10 main_board schematic added
    [main_board.kicad_pcb, main_board.sch]
2021-01-11 PCB layout added
    [main_board.sch]
2021-01-12 Main board PCB updated
    [main_board.kicad_pcb, main_board.sch]
2021-01-12 Sensors board added
    [sensors_board.kicad_pcb, sensors_board.sch]
2021-01-15 small boards update
    [main_board.kicad_pcb, sensors_board.kicad_pcb]
2021-01-16 main_baord reworked to one-side board
    [main_board.kicad_pcb, main_board.sch]
2021-01-18 Added commands to documentation
    [Documentation.ods]
2021-01-18 fix for command parser tests
    [Documentation.ods]
2021-01-19 added system reset method
    [command_parser.c, main.c]
2021-01-20 small fixes after HW check
    [bt_engine.c, i2c_driver.c, main.c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]
2021-02-12 listeners feature added to relays module
2021-02-12 listeners feature added to fan module
2021-02-12 rework of notification manager
    [main.c]
2021-02-12 Removed old documentation file
    [Documentation.ods]
2021-02-13 fix for main startup, DHT sensr match corrected
    [main.c]
2021-02-16 FAN status added to system_status message
2021-02-16 fix for reading data from application
    [wifi_driver.c]
2021-02-21 On SLM program start, it is required to power the leds via relay
2021-02-21 Fix for calculating bytes to send via I2C
    [relays_board.c, relays_board_tests.cpp]
2021-02-22 added init version of socket_driver
2021-02-22 fix for assigning sock_id in socket_driver
2021-02-22 BT engine stub reworked to use socket_driver
2021-02-25 HW stub development, I2C driver SIM version prepared
2021-02-25 DHT driver SIM version added
2021-02-25 message parsing for I2C stub added
2021-02-26 interrupt handling moved outside of inputs module
2021-02-27 dht, i2c sim versions ready, Cmakes cleanup
2021-02-27 wifi driver sim added, stm stubs updated
2021-02-27 switched SIM to main.c file, fix for crash in ENV module
    [hw_stub.c, main.c, wifi_driver.c]
2021-02-27 Fix for I2C tests after change the default stub state
2021-02-27 fix interrupt handling for inputs module
    [inputs_board_tests.cpp, inputs_interrupt_handler.c]
2021-02-28 config settings reworked, removed logs over wifi feature
    [main.c]
2021-02-28 settings reworked - moved to common project space
    [hw_stub.c]
2021-03-05 fix for wrong debug trace in hw_stub.c
    [hw_stub.c]
2021-03-05 Socket driver rework - use header before message, SHT bump
2021-03-09 Changed socket hang-up timeout to 100ms, some cleanup
2021-03-09 Newline removed from logs after changing socket sending strategy (size-based)
2021-03-09 add error log when cannot set LED step timeout
